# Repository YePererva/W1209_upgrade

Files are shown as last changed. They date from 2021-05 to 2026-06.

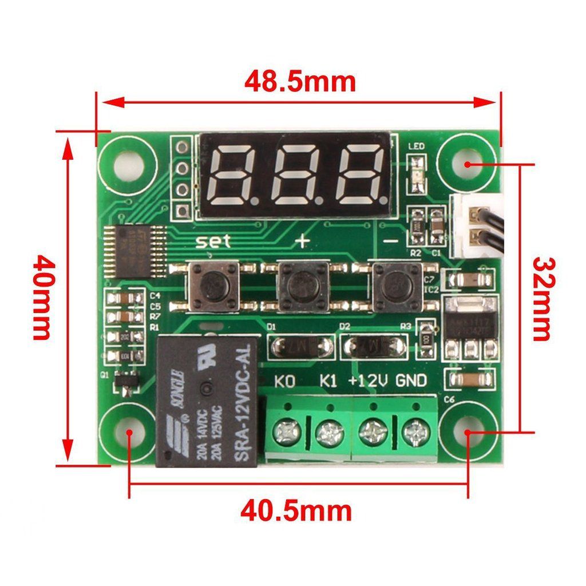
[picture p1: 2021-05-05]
references/layout/dimmension.jpg

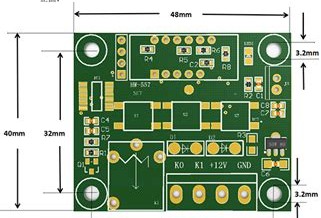
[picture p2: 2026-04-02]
references/layout/OIP-761456689.jpg

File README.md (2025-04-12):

# W1209 modification

**Repository is work in progress**

This repository contains my vision of modification of widely used W1209 thermostat.
Here, I want to introduce following changes:
- add "universal" schematic to use with either:
  - 10-20K NTC (as original W1209)
  - DS18B20
  - TMP36 and alike
  - LMx35 and alike
- add a capacitor for RESET line of to prevent self-restart\
  as reported here: [1](https://sampawno.ru/viewtopic.php?f=120&t=13251)
- Replace some custom sized SRA-12VDC-AL relay with more generiac. Like OMRON or something

# Remarks
- These thermostats were designed with [STM8S103F3P6](https://www.st.com/resource/en/datasheet/stm8s103f2.pdf) microcontrollers, but there are variations with [Nuvoton N76003AT20](https://direct.nuvoton.com/en/n76e003at20) MCU. The spare microcontroller can be salvaged from cheap STM8S103F3P6 devboards \
  (examples [1](https://vivonomicon.com/2018/07/15/the-w1209-a-sometimes-stm8-based-digital-thermostat/), [2](https://www.youtube.com/watch?v=e2FIBK9F2Js)).

# References
- The schematic of original module is "reviewed" here: \
  [1](https://chinese-electronics-products-tested.blogspot.com/p/w1209-temperature-controller-tested.html),
  [2](http://www.mastervintik.ru/obzor-tsifrovogo-modulya-termoregulyatora-w1209/),
  [3](https://tenbaht.github.io/sduino/hardware/w1209-thermostat/)

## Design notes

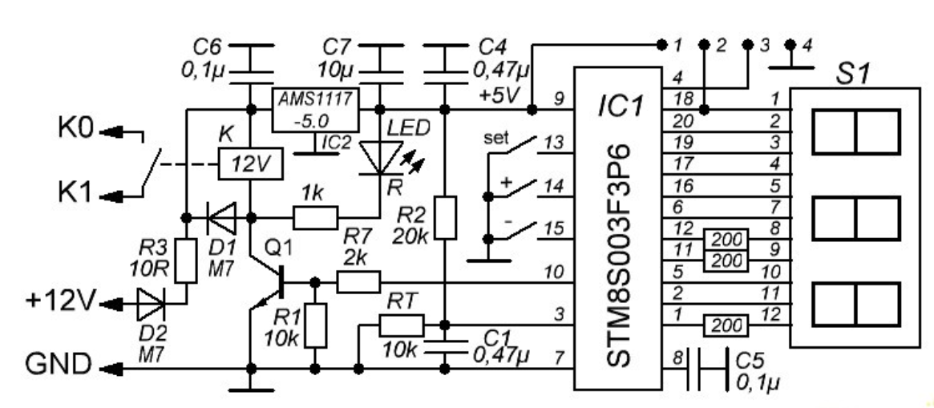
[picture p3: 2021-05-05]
references/schematics/w1209_schematics.png

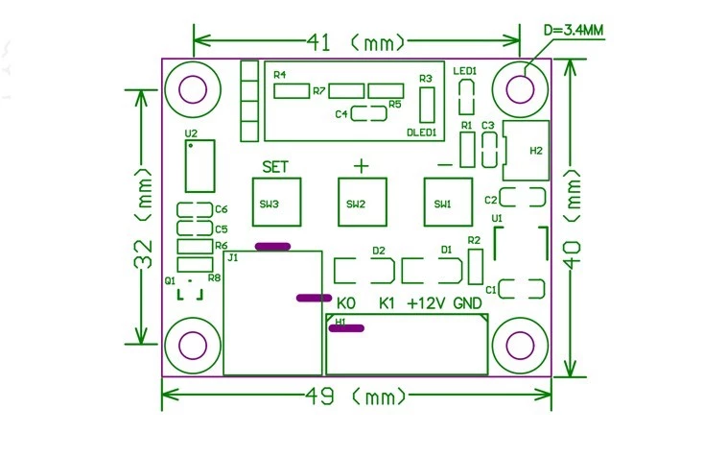
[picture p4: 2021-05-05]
references/layout/dimmension-metricwebp.webp

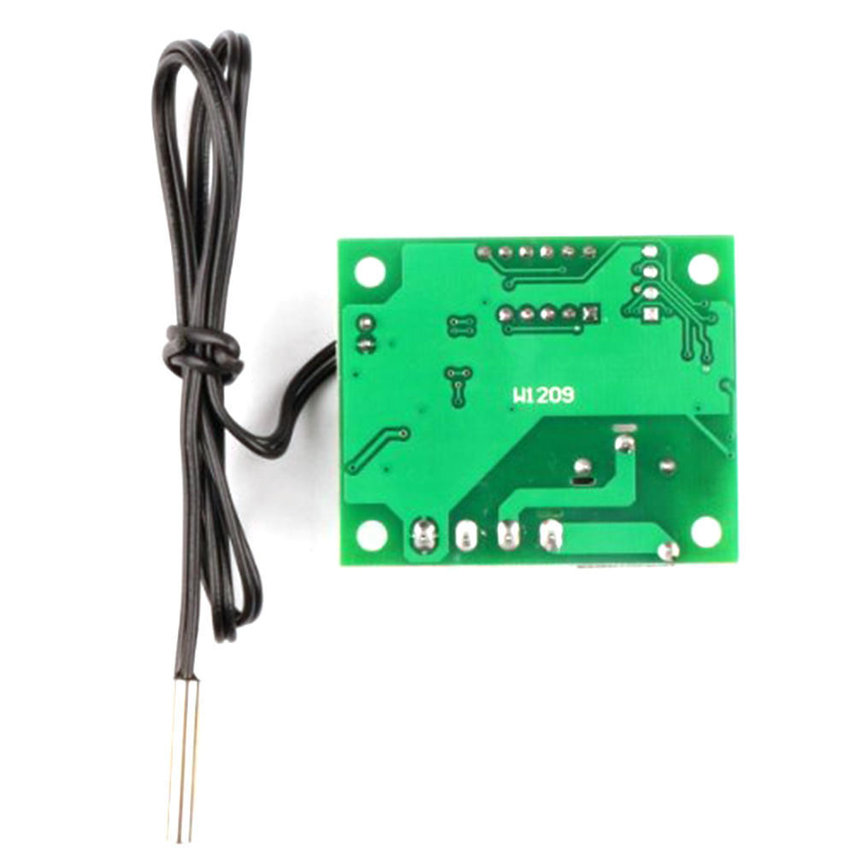
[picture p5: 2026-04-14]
references/layout/dc68eefd772fd5757c43e4a51a32627c8cdf1c95_original-3995584737.jpg

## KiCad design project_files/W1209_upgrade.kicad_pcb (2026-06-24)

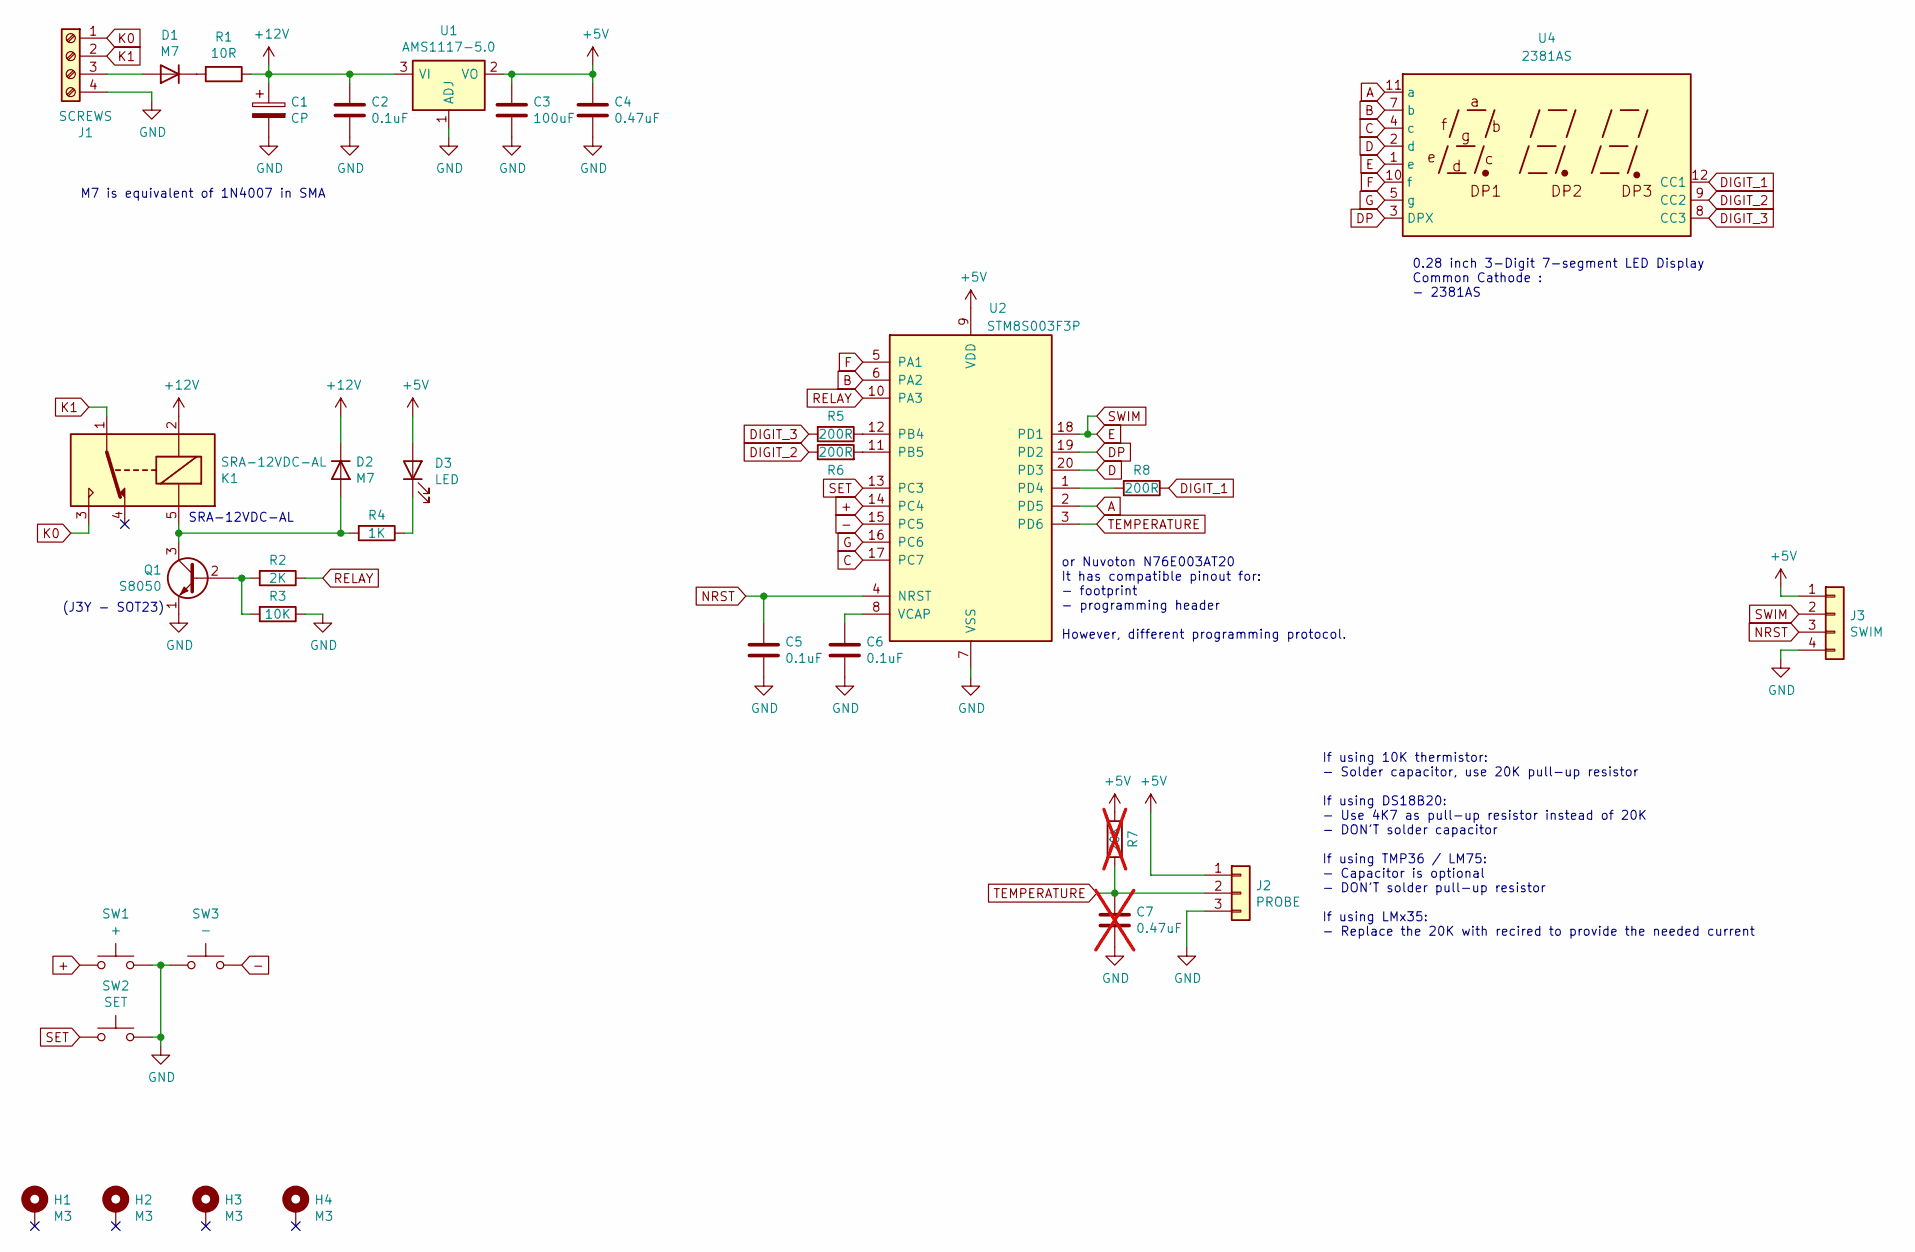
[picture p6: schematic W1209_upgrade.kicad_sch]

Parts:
C1: CP; CP_EIA-3528-12_Kemet-T_HandSolder
C2, C5, C6: 0.1uF; C_0805_2012Metric
C3: 100uF; C_0805_2012Metric
C4: 0.47uF; C_0805_2012Metric
C7: 0.47uF; C_0805_2012Metric; not fitted
D1, D2: M7; D_SMA
D3: LED; LED_0805_2012Metric
H1, H2, H3, H4: M3; MountingHole_3.2mm_M3_ISO14580_Pad
J1: SCREWS; TerminalBlock_Phoenix_PT-1,5-4-3.5-H_1x04_P3.50mm_Horizontal
J2: PROBE; PinHeader_1x03_P2.54mm_Vertical
J3: SWIM; PinHeader_1x04_P2.54mm_Vertical
K1: SRA-12VDC-AL; SRA
Q1: S8050; SOT-23
R1: 10R; R_0805_2012Metric
R2: 2K; R_0805_2012Metric
R3: 10K; R_0805_2012Metric
R4: 1K; R_0805_2012Metric
R5, R6, R8: 200R; R_0805_2012Metric
R7: 20K; R_0805_2012Metric; not fitted
SW1: +; SW_PUSH_6mm
SW2: SET; SW_PUSH_6mm
SW3: -; SW_PUSH_6mm
U1: AMS1117-5.0; SOT-223-3_TabPin2
U2: STM8S003F3P; TSSOP-20_4.4x6.5mm_P0.65mm
U4: 2381AS; 2381

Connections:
+: SW1.1, U2.14 (PC4)
+5V: C3.1, C4.1, D3.2 (A), J2.1, J3.1, R7.1, U1.2 (VO), U2.9 (VDD)
+12V: C1.1, C2.1, D2.1 (K), K1.2, R1.1, U1.3 (VI)
-: SW3.1, U2.15 (PC5)
A: U2.2 (PD5), U4.11 (a)
B: U2.6 (PA2), U4.7 (b)
C: U2.17 (PC7), U4.4 (c)
D: U2.20 (PD3), U4.2 (d)
DIGIT_1: R8.1, U4.12 (CC1)
DIGIT_2: R6.1, U4.9 (CC2)
DIGIT_3: R5.2, U4.8 (CC3)
DP: U2.19 (PD2), U4.3 (DPX)
E: J3.2, U2.18 (PD1), U4.1 (e)
F: U2.5 (PA1), U4.10 (f)
G: U2.16 (PC6), U4.5 (g)
GND: C1.2, C2.2, C3.2, C4.2, C5.2, C6.2, C7.2, J1.4, J2.3, J3.4, Q1.1 (E), R3.1, SW1.2, SW2.2, SW3.2, U1.1 (ADJ), U2.7 (VSS)
K0: J1.1, K1.3
K1: J1.2, K1.1
NRST: C5.1, J3.3, U2.4 (NRST)
unnamed: D1.2 (A), J1.3
unnamed: D1.1 (K), R1.2
unnamed: D2.2 (A), K1.5, Q1.3 (C), R4.2
unnamed: D3.1 (K), R4.1
unnamed: Q1.2 (B), R2.2, R3.2
unnamed: R5.1, U2.12 (PB4)
unnamed: R6.2, U2.11 (PB5)
unnamed: R8.2, U2.1 (PD4)
unnamed: C6.1, U2.8 (VCAP)
RELAY: R2.1, U2.10 (PA3)
SET: SW2.1, U2.13 (PC3)
TEMPERATURE: C7.1, J2.2, R7.2, U2.3 (PD6)

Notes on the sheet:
If using 10K thermistor: - Solder capacitor, use 20K pull-up resistor If using DS18B20: - Use 4K7 as pull-up resistor instead of 20K - DON'T solder capacitor If using TMP36 / LM75: - Capacitor is optional - DON'T solder pull-up resistor If using LMx35: - Replace the 20K with recired to provide the 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
or Nuvoton N76E003AT20 It has compatible pinout for: - footprint - programming header However, different programming protocol.
M7 is equivalent of 1N4007 in SMA
0.28 inch 3-Digit 7-segment LED Display Common Cathode : - 2381AS
(J3Y - SOT23)
SRA-12VDC-AL

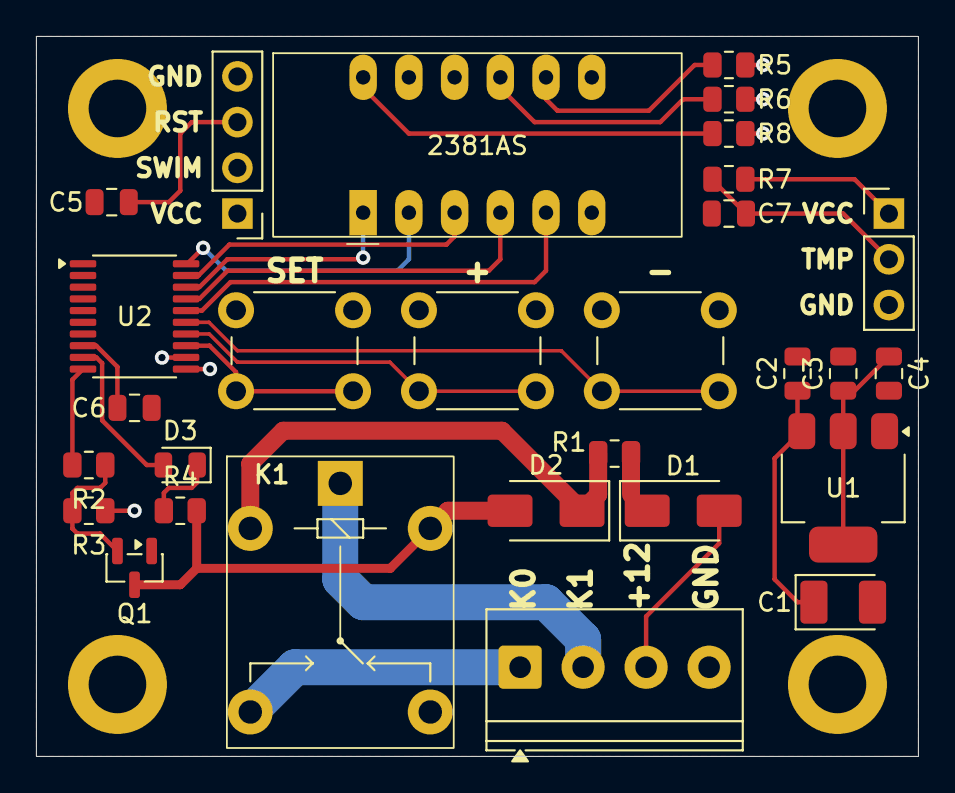
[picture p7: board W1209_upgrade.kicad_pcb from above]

Board: 2 copper layers, 49.0 x 40.0 mm, 33 parts (0 on the bottom side), 31 nets.

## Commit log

2021-06-16 Comments correction
    [W1209_upgrade.kicad_pcb, W1209_upgrade.kicad_sch, W1209_upgrade.sch]
2025-04-12 Reopened in the recent kicad
    [W1209_upgrade.kicad_pcb, W1209_upgrade.kicad_sch]
2025-04-12 added a few datasheets
    [W1209_upgrade.kicad_sch]
2026-04-02 updated to KiCAD 10
    [W1209_upgrade.kicad_pcb, W1209_upgrade.kicad_sch]
2026-06-24 COnverted to KiCAD 10.0.4
    [W1209_upgrade.kicad_pcb]
